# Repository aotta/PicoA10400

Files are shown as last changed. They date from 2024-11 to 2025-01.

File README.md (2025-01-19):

# PicoA10400
Flashcart for Atari 2600 and Atari 7800 based on Pico "Purple" clone, easy to build and cheap.
This is a "double-face" flashcart, it could be used for both Atari 2600 and Atari 7800, simply rotating it and inserting the cart in different Atari!!
It doesn't support all bank-switching schemas, but enough to enjoy your A2600 / A7800 with a single flash-carts!!

A special thanks to other opensource project for Atari multicarts from which i got a lot of info, ideas and also code:
https://github.com/robinhedwards/UnoCart-2600

https://github.com/karrika/Otaku-flash

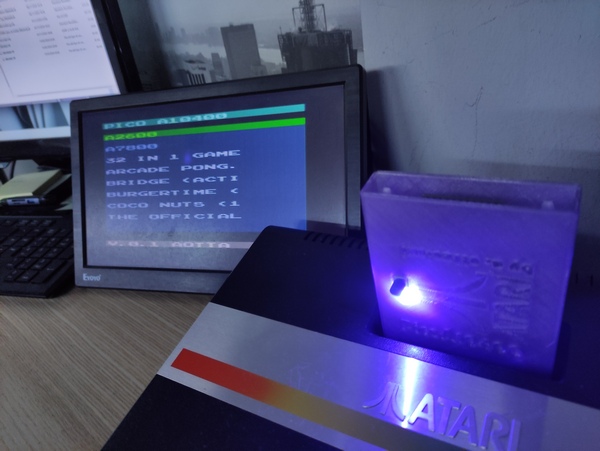
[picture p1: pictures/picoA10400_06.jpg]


**WARNING!** "purple" Pico has not the same pinout of original Raspberry "green" ones, you MUST use the clone or you may damage your hardware.
Also note that the battery used is a RECHARGEABLE LIR2032, if you want to use a NON reachargeable battery you must add a diode in circuit!!!

Tested only on PAL consoles so far, feel free to send comments and feedback on AtariAge thread:
https://forums.atariage.com/topic/374297-picoa10400-preview/

**NOTE** Please look at picture for soldering side of the components, or your shell won't close!! they are different from the pcb mask!!!

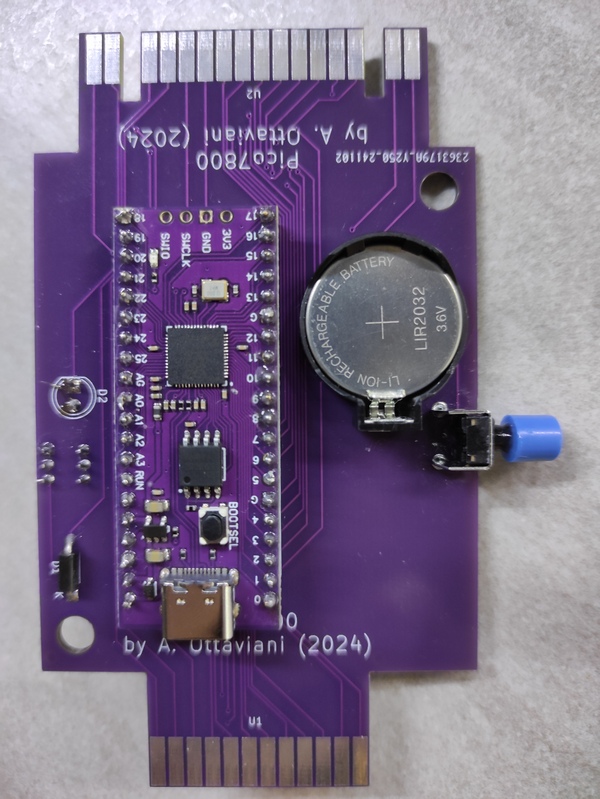
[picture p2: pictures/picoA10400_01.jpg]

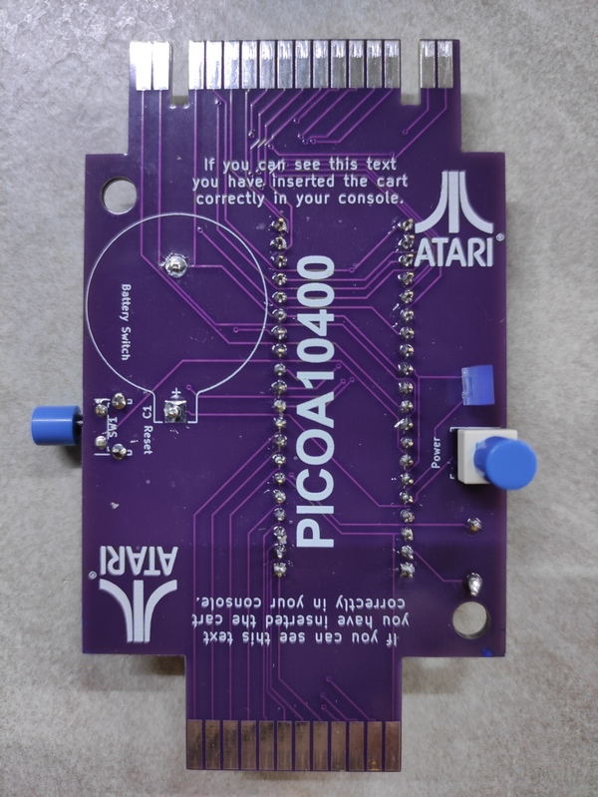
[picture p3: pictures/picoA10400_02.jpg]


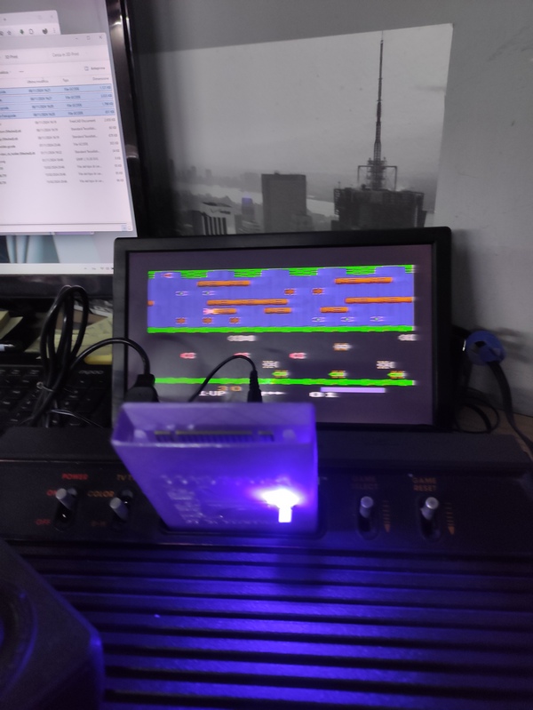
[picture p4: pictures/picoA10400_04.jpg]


Also added a Raspberry Pico 2 version, relative files are named Pico2A10400. It works but consider its smaller flash size for roms (3mb):

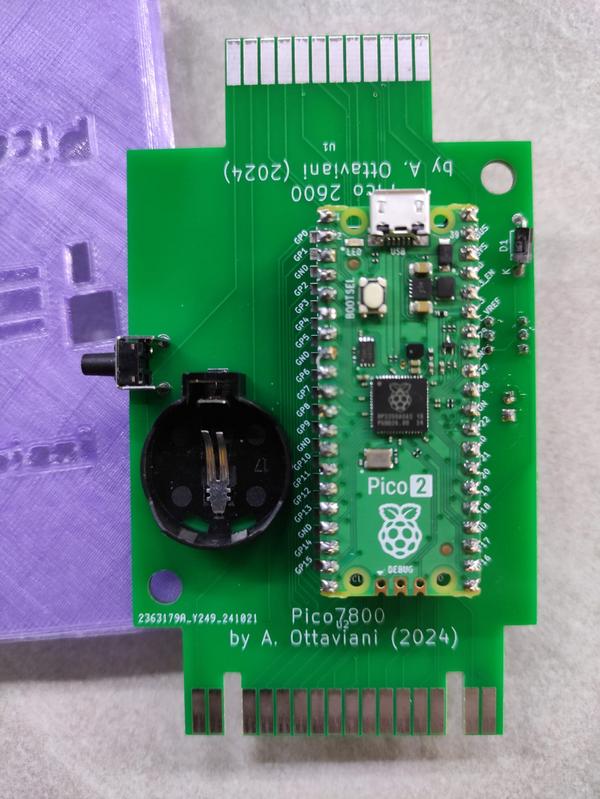
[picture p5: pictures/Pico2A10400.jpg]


Gerbers file are provided for the PCB, add you pico clone, and flash the firmware ".uf2" in the Pico by connecting it while pressing button on Pico and drop it in the opened windows on PC.
After flashed with firmware, and every time you have to change your ROMS repository, you can simply connect the Pico to PC and drag&drop "BIN" files  into.

**NOTE 2** Due to different timing of PicoA10400 and the Atari consoles, that can't be resetted, the flashcart MUST BE POWERED ON (with POWER SWITCH ON CART) BEFORE POWERING THE CONSOLE!!! Also, some games and ALL A7800 GAMES NEEDS THAT THE CONSOLE IS POWERED OFF THEN POWERED ON TO START!!!!

Even if the diode should protect your console, **DO NOT CONNECT PICO WHILE INSERTED IN A POWERED ON CONSOLE!**

19th january 2025: added Pico 10400 Alternative Version by XAD, with improvements in pcb and shell: https://www.nightfallcrew.com/17/01/2025/picoa10400-flashcart-for-atari-2600-7800/
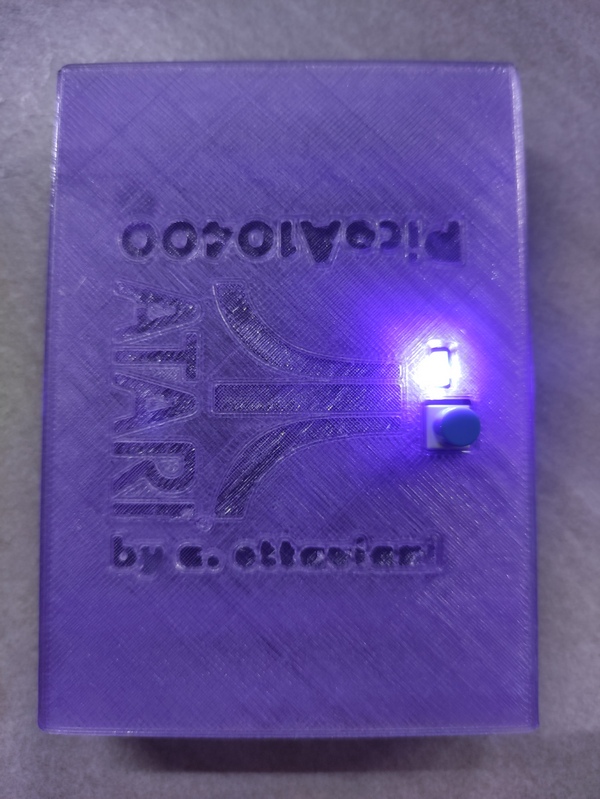
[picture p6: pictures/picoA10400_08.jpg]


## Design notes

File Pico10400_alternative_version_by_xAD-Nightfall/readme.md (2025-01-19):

3D Printer Model: Flsun v400
Filament: PLA+

Screws and micro switches:

M2 screws with countersunk head: https://www.amazon.it/dp/B0D3DXFGHW
Mini SPDT Switch: https://www.amazon.it/dp/B0BTM3WQXN

The LED source voltage is 3.3v from PIN 36 of the PICO Purple.

LED Resistor:

RED/YELLOW LED: 100ohm
GREEN LED: 75ohm
BLU/WHITE: No Resistor (solder a bridge instead of resistor)

Pico 10400 Main Project: https://github.com/aotta/PicoA10400
Pico 10400 Alternative Version: https://www.nightfallcrew.com/17/01/2025/picoa10400-flashcart-for-atari-2600-7800/

Xad/Nightfall

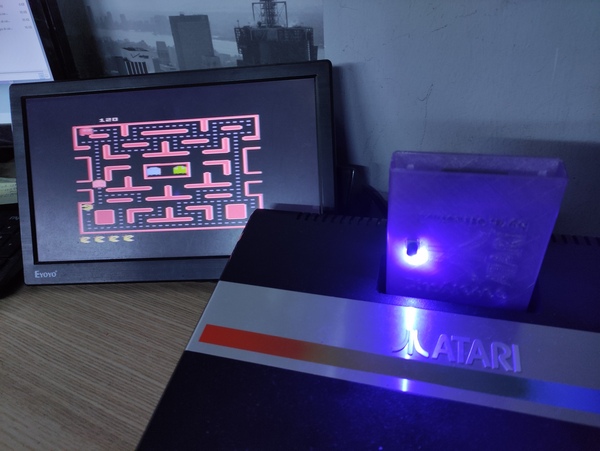
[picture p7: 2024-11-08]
pictures/picoA10400_11.jpg

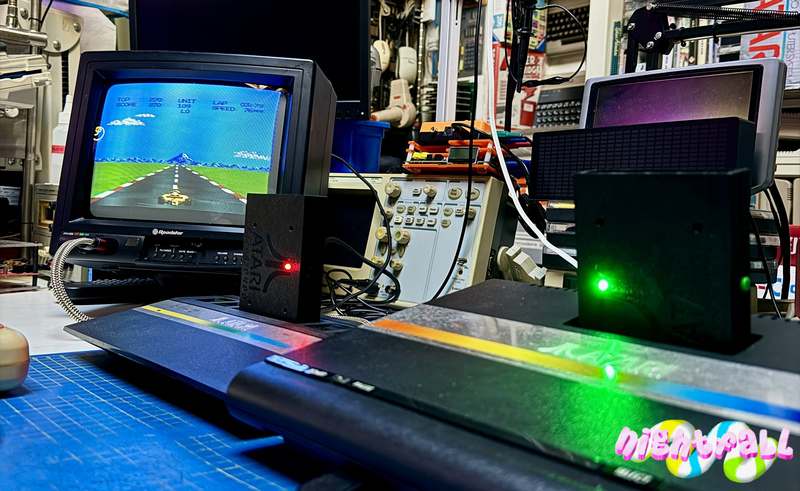
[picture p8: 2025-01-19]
pictures/picoA10400_09.jpg

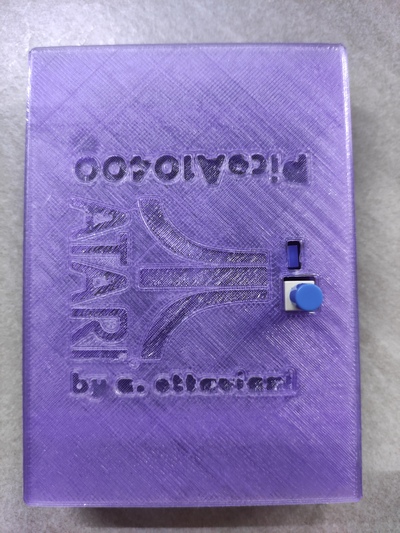
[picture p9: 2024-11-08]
pictures/picoA10400_07.jpg

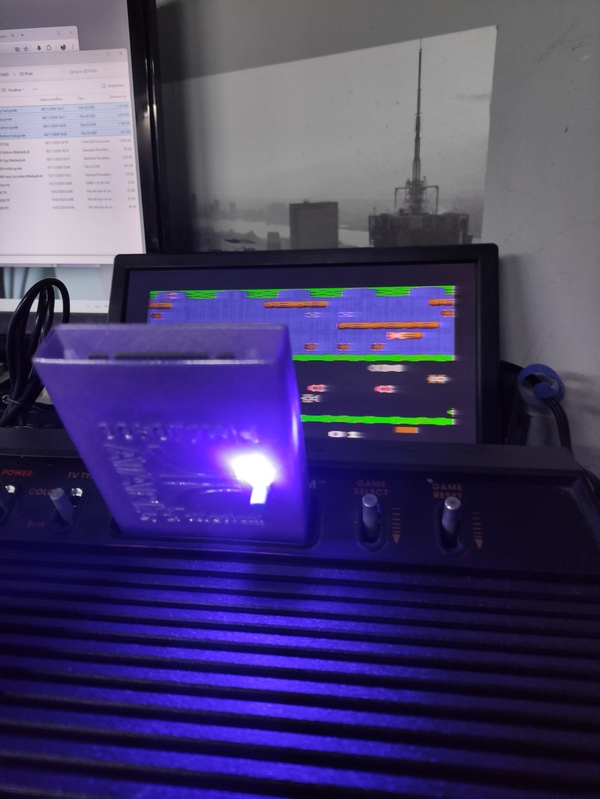
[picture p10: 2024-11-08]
pictures/picoA10400_05.jpg

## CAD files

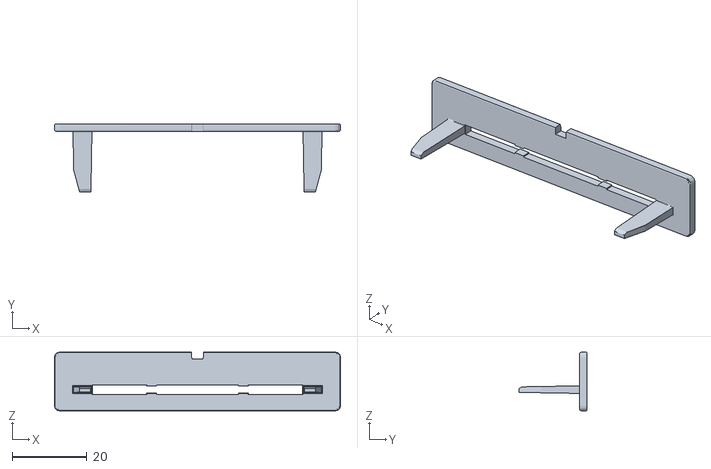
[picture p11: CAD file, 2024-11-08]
3D Print/PicoA10400-atari_cb_holder (Meshed).stl
76.4 x 18.3 x 15.7

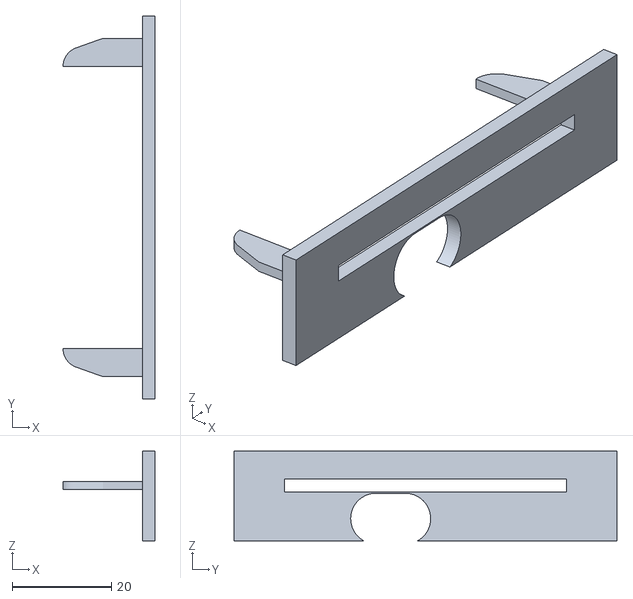
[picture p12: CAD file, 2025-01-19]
Pico10400_alternative_version_by_xAD-Nightfall/Stl/Holder usb.stl
18.5 x 77.0 x 18.0

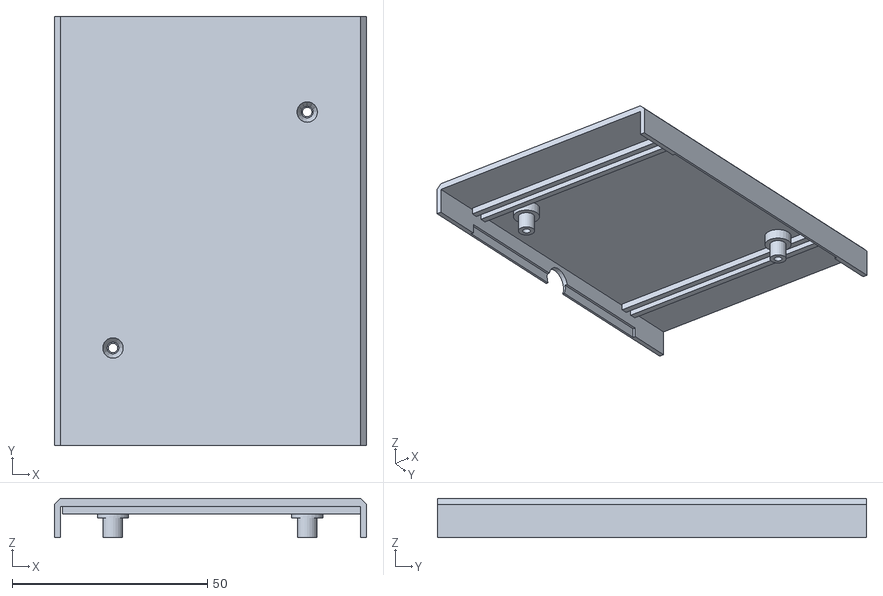
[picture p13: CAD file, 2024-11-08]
3D Print/PicoA10400-Bottom (Meshed).stl
80.0 x 110.0 x 10.0

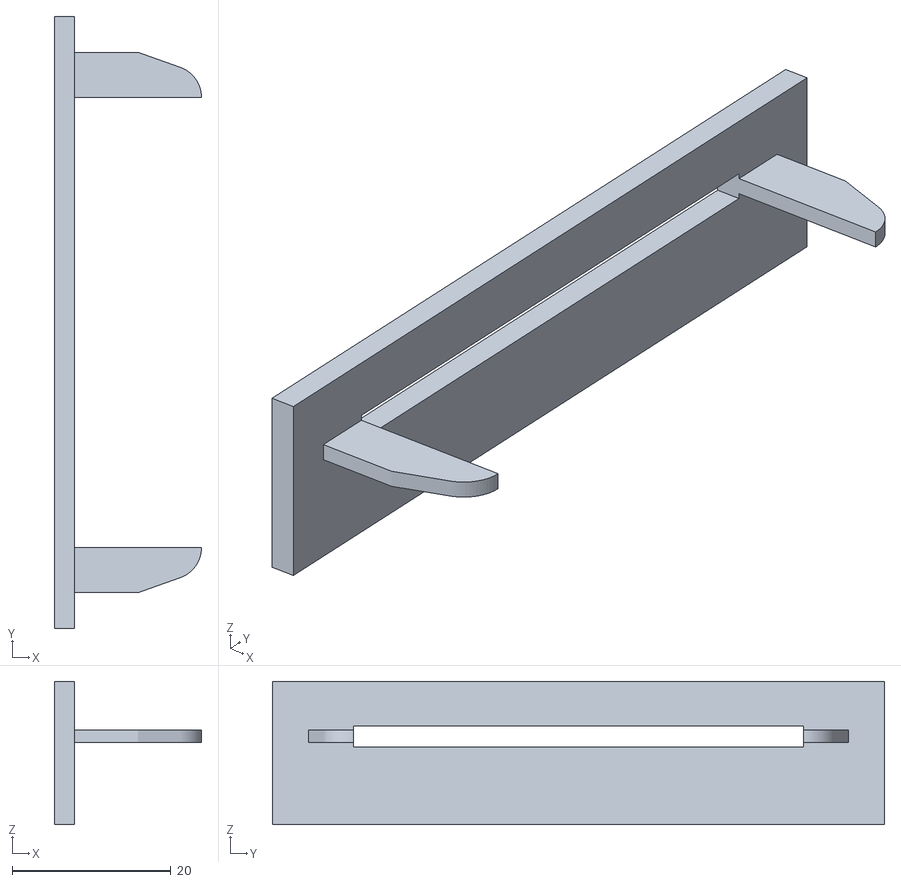
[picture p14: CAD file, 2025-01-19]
Pico10400_alternative_version_by_xAD-Nightfall/Stl/Holder.stl
18.5 x 77.0 x 18.0

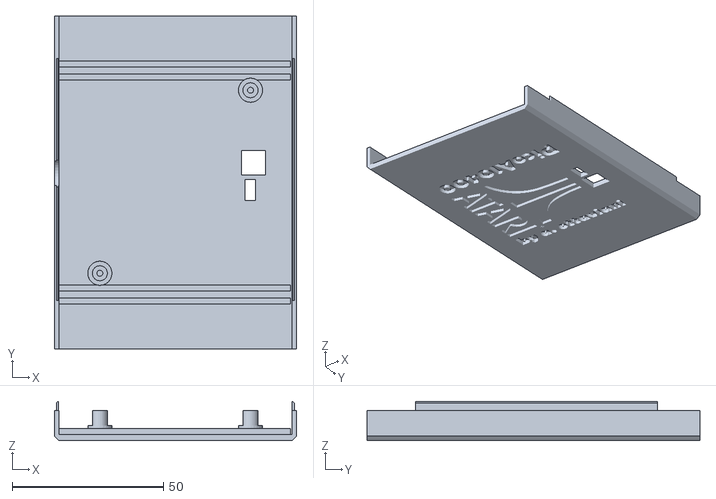
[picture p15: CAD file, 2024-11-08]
3D Print/PicoA10400-Top (Meshed).stl
80.0 x 110.0 x 13.0

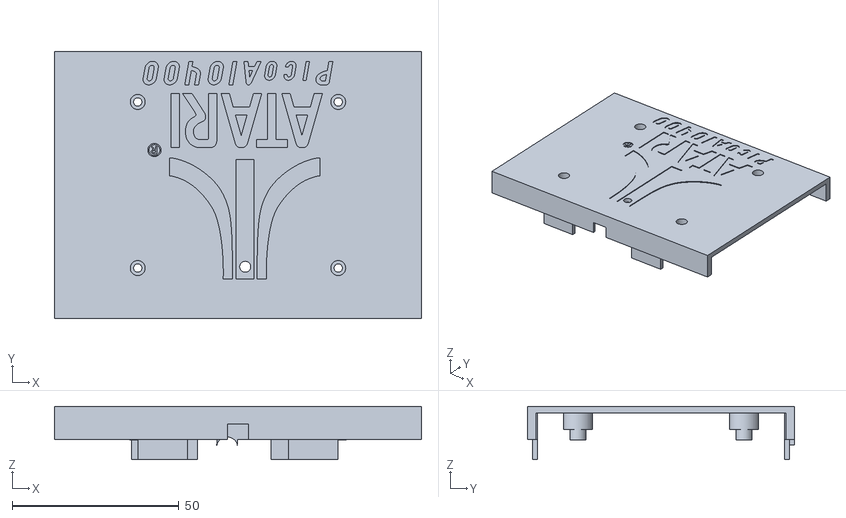
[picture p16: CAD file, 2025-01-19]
Pico10400_alternative_version_by_xAD-Nightfall/Stl/Top.stl
110.0 x 80.0 x 16.0

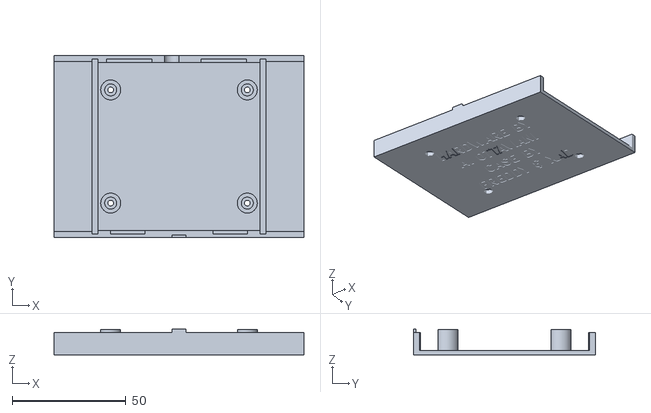
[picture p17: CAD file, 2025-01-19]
Pico10400_alternative_version_by_xAD-Nightfall/Stl/Bottom.stl
110.0 x 80.0 x 11.4

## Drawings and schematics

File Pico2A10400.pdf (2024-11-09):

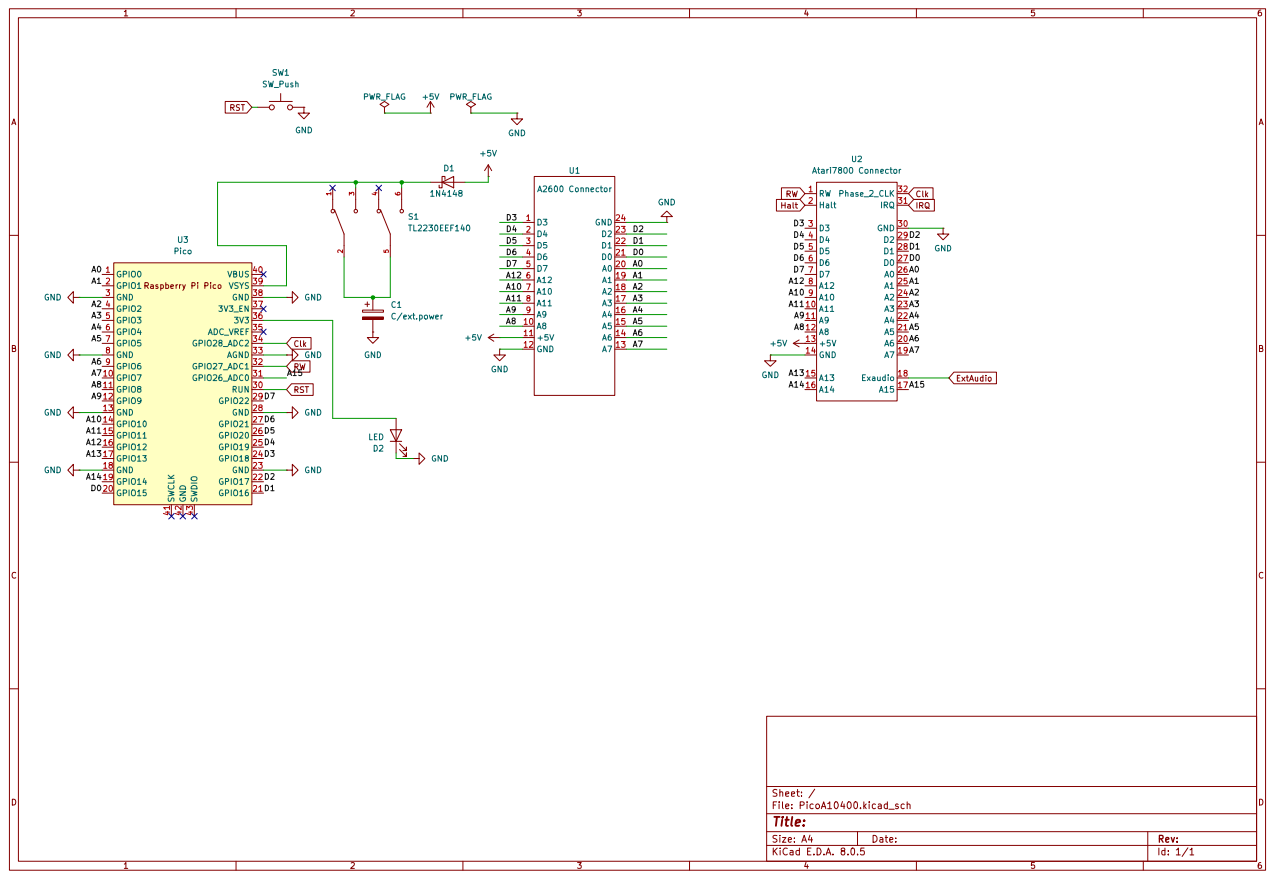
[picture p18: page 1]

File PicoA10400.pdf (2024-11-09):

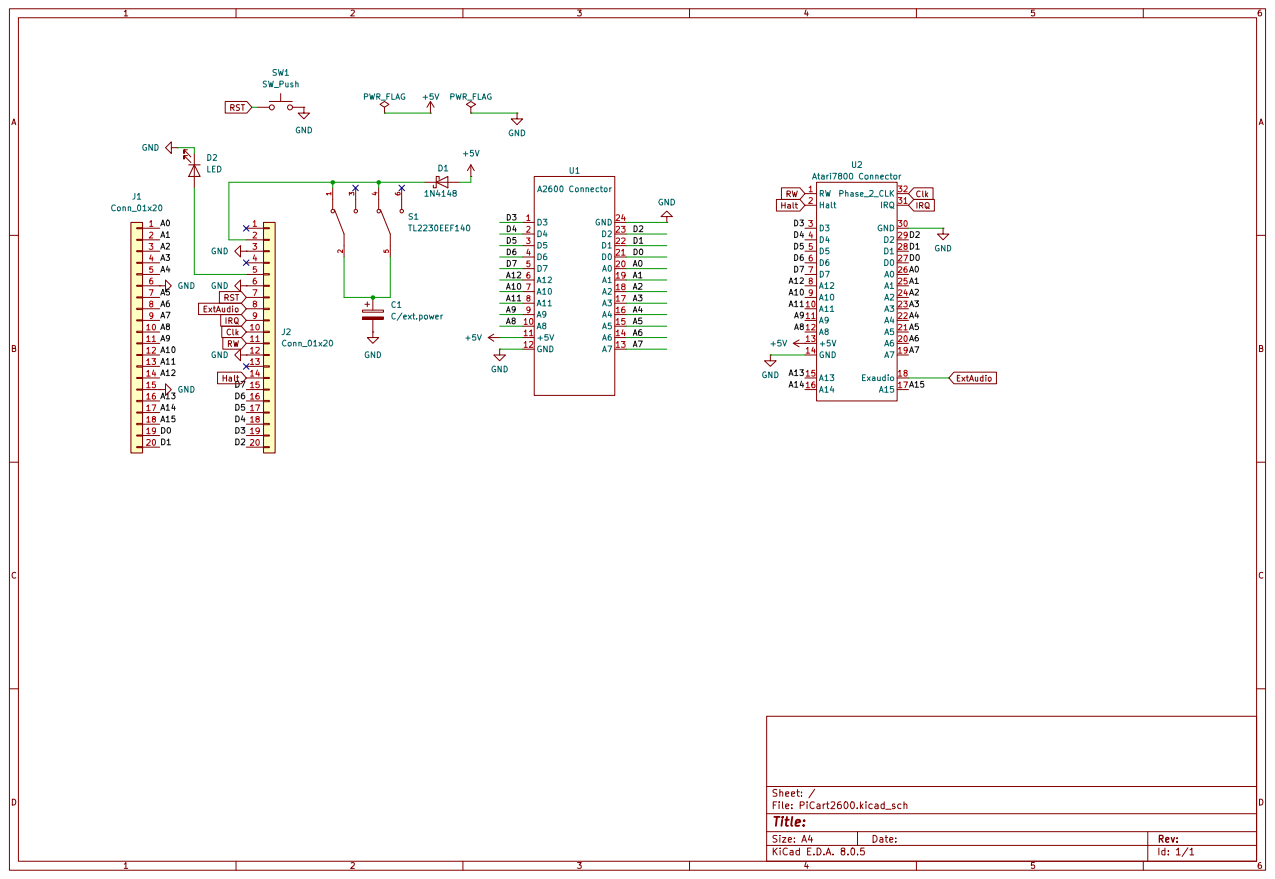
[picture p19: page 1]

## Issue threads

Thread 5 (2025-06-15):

Not filesystem

yoprogramo, 2025-06-15:
I have mounted the card and flashed the uf2 and the unit appears but without filesystem. Do I need to format it?

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

aotta, 2025-06-15:
some users reported issue in detecting flash in non "windows" systems. Please use PC with MS Windows OS for loading roms.

yoprogramo, 2025-06-15:
I have not a windows machine and I don't wanna to buy one for this. I'll try to enhance the code to avoid this dependency if it is possible.

Thank you

yoprogramo, 2025-06-17:
I'm trying to compile the code using platformio but I have errors compiling the libraries used. Do you have some instructions on compiling it?

Regards

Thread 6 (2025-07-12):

No Menu with 2600+

JmanNZ, 2025-07-12:
No menu with Atari 2600+.
1st game in the list loads and plays fine

Regards

aotta, 2025-07-12:
I have no 2600+ to test, but other users reported PicoA10400 worked fine with it

douglie007, 2025-08-04:
I also have the same issue with the 2600+.  only way I can play a game on it  would be to load the game on an original console, leave the cart on and boot it in the 2600+ and it will pull the game.  but I don't know how you could use the menu in a 2600+ because the console just rips the ROM from the cart and loads it up in Stella emulator, it would have to be able to rip the menu and all the games on the Pico.

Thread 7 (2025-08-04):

Testing 7800 side of cart has issues.

douglie007, 2025-08-04:
When I try and load a 7800 game, if I use the .BIN i just get noise, If I use the .a78 files I can boot the game after power cycling the console. Even so the games that are at 128K have a hard time playing.  I couldnt find a instruction manual on what to expect, this i might be normal.    A request would be, can the games be saved in a ROM instead of in the RAM?  It would be nice if it held the game in a state where you dont need to worry about the battery it would would on the 2600+ and 7800+.

Thanks for the great work youve done with this!

Closed 2025-08-04.

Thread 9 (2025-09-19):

Add support for the A7800+ and A2600+

SolverTwins, 2025-09-19:
Thanks for your fabulous Job, I will trying to modify, adding support for the a7800+ and a2600+, my solution is add a 2 lines LCD panel (I2C) connected directly to the PICO and obtain the 5v from the cart/console , and add 3 buttons to navigate in the LCD, so you can select the game to be presented to the console, and you only need then to reset the console (not the a10400) and voila the game will work, I think that its posible, please can you tell me what do you think, THANKS

aotta, 2025-09-20:
Yes, it's possible in theory, but it would be a massive change in logic, code and scope of the project.
I'm not interested in supporting new consoles nor i have a "+" Atari emulator, but source are here if someone want to use it for a a2600+ or a7800+ project.

Closed 2025-09-20.

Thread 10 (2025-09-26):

Power and alternate microcontroller question.

MarkMccabe, 2025-09-26:
More of some questions instead of "hard issues".
A) If I use a PICO2 instead of the A10400 do I still need to make sure it is powered up before the Atari console or is that just a A10400 issue?
B) I already have a batch of Raspberry Pi Picos. Can I use them instead of the Pico2 even though they are a bit slower. (Actually I have the Chinese clone of the Pi Pico with the multicolor LED and larger program storage space)
C) Also my machines are NTSC. Has the NTSC menu open issue been resolved or should I wait until it is before procuring and building these?
A big thank you for designing this!!! I will build some of them as soon as I know if the menu works on NTSC. Wonderful Project!!! Thanks again!!!

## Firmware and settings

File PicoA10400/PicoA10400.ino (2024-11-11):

/*
//            PICO A10400 an Atari 2600+7800 MultiCART by Andrea Ottaviani 
// Atari 2600 / Atari 7800   multicart based on Raspberry Pico board -

// v. 0.1 2024-10-03 : Initial version for Pi Pico 
//
// 
//  More info on https://github.com/aotta/ 
*/

#include "hardware/gpio.h"
#include "pico/platform.h"
#include "pico/stdlib.h"
#include "hardware/vreg.h"
#include "pico/multicore.h"
#include "hardware/flash.h"
#include "hardware/sync.h"
#include "string.h"
#include "rom.h"
//#include "menu7800.h"

// include for Flash files
#include "SPI.h"
#include "SdFat.h"
#include "Adafruit_SPIFlash.h"
#include "Adafruit_TinyUSB.h"
#include "supercharger_bios.h"
Adafruit_FlashTransport_RP2040 flashTransport;
Adafruit_SPIFlash flash(&flashTransport);

// file system object from SdFat
FatVolume fatfs;
FatFile root;
FatFile file;

// USB Mass Storage object
Adafruit_USBD_MSC usb_msc;
// Check if flash is formatted
bool fs_formatted;
// Set to true when PC write to flash
bool fs_changed;

#define a7800    0   // 1 for 7800 menu, 0 for 2600

// Pico pin usage definitions

#define A0_PIN    0
#define A1_PIN    1
#define A2_PIN    2
#define A3_PIN    3
#define A4_PIN    4
#define A5_PIN    5
#define A6_PIN    6
#define A7_PIN    7
#define A8_PIN    8
#define A9_PIN    9
#define A10_PIN  10
#define A11_PIN  11
#define A12_PIN  12
#define A13_PIN  13
#define A14_PIN  14
#define A15_PIN  15
#define D0_PIN   16
#define D1_PIN   17
#define D2_PIN   18
#define D3_PIN   19
#define D4_PIN   20
#define D5_PIN   21
#define D6_PIN   22
#define D7_PIN   23
#define HALT_PIN 24
#define RW_PIN   26
#define CLK_PIN  27
#define IRQ_PIN  28

// Pico pin usage masks
#define A0_PIN_MASK     0x00000001L //gpio 0
#define A1_PIN_MASK     0x00000002L
#define A2_PIN_MASK     0x00000004L
#define A3_PIN_MASK     0x00000008L
#define A4_PIN_MASK     0x00000010L
#define A5_PIN_MASK     0x00000020L
#define A6_PIN_MASK     0x00000040L
#define A7_PIN_MASK     0x00000080L
#define A8_PIN_MASK     0x00000100L
#define A9_PIN_MASK     0x00000200L
#define A10_PIN_MASK    0x00000400L
#define A11_PIN_MASK    0x00000800L
#define A12_PIN_MASK    0x00001000L  //  
#define A13_PIN_MASK    0x00002000L  //  
#define A14_PIN_MASK    0x00004000L  //  
#define A15_PIN_MASK    0x00008000L  //  
#define D0_PIN_MASK     0x00010000L
#define D1_PIN_MASK     0x00020000L
#define D2_PIN_MASK     0x00040000L
#define D3_PIN_MASK     0x00080000L
#define D4_PIN_MASK     0x00100000L  // gpio 20
#define D5_PIN_MASK     0x00200000L
#define D6_PIN_MASK     0x00400000L
#define D7_PIN_MASK     0x00800000L //gpio 23
#define HALT_PIN_MASK   0x01000000L //gpio 24
#define LED_PIN_MASK    0x02000000L //gpio 25
#define RW_PIN_MASK     0x04000000L //gpio 26
#define CLK_PIN_MASK    0x08000000L //gpio 27
#define IRQ_PIN_MASK    0x10000000L //gpio 28


// Aggregate Pico pin usage masks
#define ALL_GPIO_MASK  	0x1FFFFFFFL
#define BUS_PIN_MASK    0x0000FFFFL
#define BUS_H_PIN_MASK  0x0000E000L
#define DATA_PIN_MASK   0x00FF0000L
#define STATUS_PIN_MASK 0x1D000000L
#define READ_PIN_MASK    (A14_PIN_MASK | A15_PIN_MASK | RW_PIN_MASK)  //gpio 27

#define ALWAYS_IN_MASK  (BUS_PIN_MASK | STATUS_PIN_MASK)
#define ALWAYS_OUT_MASK (DATA_PIN_MASK)

#define SET_DATA_MODE_OUT   gpio_set_dir_out_masked(DATA_PIN_MASK)
#define SET_DATA_MODE_IN    gpio_set_dir_in_masked(DATA_PIN_MASK)

#define SET_LED_ON    	gpio_init(25);gpio_set_dir(25,GPIO_OUT);gpio_put(25,true);
#define SET_LED_OFF    	gpio_init(25);gpio_set_dir(25,GPIO_OUT);gpio_put(25,false);



#define CART_TYPE_NONE	0
#define CART_TYPE_2K	1
#define CART_TYPE_4K	2
#define CART_TYPE_F8	3	// 8k
#define CART_TYPE_F6	4	// 16k
#define CART_TYPE_F4	5	// 32k
#define CART_TYPE_F8SC	6	// 8k+ram
#define CART_TYPE_F6SC	7	// 16k+ram
#define CART_TYPE_F4SC	8	// 32k+ram
#define CART_TYPE_FE	9	// 8k
#define CART_TYPE_3F	10	// varies (examples 8k)
#define CART_TYPE_3E	11	// varies (only example 32k)
#define CART_TYPE_3EX   12
#define CART_TYPE_E0	13	// 8k
#define CART_TYPE_0840	14	// 8k
#define CART_TYPE_CV	15	// 2k+ram
#define CART_TYPE_EF	16	// 64k
#define CART_TYPE_EFSC	17	// 64k+ram
#define CART_TYPE_F0	18	// 64k
#define CART_TYPE_FA	19	// 12k
#define CART_TYPE_E7	20	// 16k+ram
#define CART_TYPE_DPC	21	// 8k+DPC(2k)
#define CART_TYPE_AR	22  // Arcadia Supercharger (variable size)
#define CART_TYPE_BF	23  // BF
#define CART_TYPE_BFSC	24  // BFSC
#define CART_TYPE_ACE	25  // ARM Custom Executable
#define CART_TYPE_PP    26  // Pink Panther Prototype
#define CART_TYPE_DF    27  // DF
#define CART_TYPE_DFSC  28  // DFSC
#define CART_TYPE_3EP	29	// 3E+ 1-64K + 32K ram
#define CART_TYPE_4KSC  30  // 4k+SC
#define CART_TYPE_FA2	31	// 28k
#define CART_TYPE_A78	32	// Atari 7800
#define CART_TYPE_NORMALA78	33	// Atari 7800
#define CART_TYPE_ABSOLUTE	34	// Atari 7800
#define CART_TYPE_ACTIVISION	35	// Atari 7800
#define CART_TYPE_SUPERCART_EF	36	// Atari 7800 supercart EX-FIX
#define CART_TYPE_SUPERCART_ROM	37	// Atari 7800
#define CART_TYPE_SUPERCART_RAM	38	// Atari 7800
#define CART_TYPE_SUPERCART_LARGE	39	// Atari 7800
#define CART_TYPE_SUPERCART	40	// Atari 7800 supercart bs

#define CCM_RAM ((uint8_t*)0x10000000)
#define CCM_SIZE (64 * 1024)

#define RAM_BANKS 48
#define CCM_BANKS 32

#define MAX_RAM_BANK (RAM_BANKS - 1)
#define MAX_CCM_BANK (MAX_RAM_BANK + CCM_BANKS)

typedef struct __attribute__((packed)) {
	uint8_t entry_lo;
	uint8_t entry_hi;
	uint8_t control_word;
	uint8_t block_count;
	uint8_t checksum;
	uint8_t multiload_id;
	uint8_t progress_bar_speed_lo;
	uint8_t progress_bar_speed_hi;
	uint8_t padding[8];
	uint8_t block_location[48];
	uint8_t block_checksum[48];
} LoadHeader;

typedef struct __attribute__((packed)) {
	uint8_t magic_number[8]; // Always ascii "ACE-2600"
	uint8_t driver_name[16]; // emulators care about this
	uint32_t driver_version; // emulators care about this
	uint32_t rom_size;		 // size of ROM to be copied to flash, 448KB max
	uint32_t rom_checksum;	 // used to verify if flash already contains valid image
	uint32_t entry_point;	 // where to begin executing
} ACEFileHeader;

typedef struct {
	const char *ext;
	int cart_type;
} EXT_TO_CART_TYPE_MAP;

EXT_TO_CART_TYPE_MAP ext_to_cart_type_map[] = {
	{"ROM", CART_TYPE_NONE},
	{"BIN", CART_TYPE_NONE},
	{"A26", CART_TYPE_NONE},
	{"2K", CART_TYPE_2K},
	{"4K", CART_TYPE_4K},
	{"F8", CART_TYPE_F8},
	{"F6", CART_TYPE_F6},
	{"F4", CART_TYPE_F4},
	{"F8S", CART_TYPE_F8SC},
	{"F6S", CART_TYPE_F6SC},
	{"F4S", CART_TYPE_F4SC},
	{"FE", CART_TYPE_FE},
	{"3F", CART_TYPE_3F},
	{"3E", CART_TYPE_3E},
	{"3EX", CART_TYPE_3E},
	{"3EP", CART_TYPE_3EP},
	{"E0", CART_TYPE_E0},
	{"084", CART_TYPE_0840},
	{"CV", CART_TYPE_CV},
	{"EF", CART_TYPE_EF},
	{"EFS", CART_TYPE_EFSC},
	{"F0", CART_TYPE_F0},
	{"FA", CART_TYPE_FA},
	{"E7", CART_TYPE_E7},
	{"DPC", CART_TYPE_DPC},
	{"AR", CART_TYPE_AR},
	{"BF", CART_TYPE_BF},
	{"BFS", CART_TYPE_BFSC},
	{"ACE", CART_TYPE_ACE},
	{"WD", CART_TYPE_PP},
	{"DF", CART_TYPE_DF},
	{"DFS", CART_TYPE_DFSC},
	{"4KSC", CART_TYPE_4KSC},
  {"FA2", CART_TYPE_FA2},
  {"A78", CART_TYPE_A78},
	{0,0}
};

//#define rom_table_SIZE			128  // kilobytes
unsigned int cart_size_bytes;

//unsigned char rom_table[32*1024];
char menu_status[16];
uint8_t AR_ROM[8448*4];
char filelist[85*48]; // 85 name of 48 chars max lenght
uint8_t ram_table[32*1024];
char path[128];
 char filetoopen[50];
 
char menu_ram[1024];	// < NUM_DIR_ITEMS * 12 (85 max)
char isfor7800=0;
char is16k=0;
int romsize;
int lastpos;
volatile u_int8_t bank_type=1;
volatile u_int8_t new_bank_type=1;
volatile int romLen=0;
u_int8_t gamechoosen=0;
volatile u_int8_t newgame=0;
volatile u_int8_t rootdir=0;
volatile uint32_t addrc;
volatile uint32_t retaddr;
volatile u_int8_t cart_to_emulate;
  
////////////////////////////////////////////////////////////////////////////////////
//                     REBOOT
////////////////////////////////////////////////////////////////////////////////////
void doReboot() {
  rp2040.reboot();
}
////////////////////////////////////////////////////////////////////////////////////
//                     EXIT CARTRIDGE
////////////////////////////////////////////////////////////////////////////////////

void exit_cartridge(uint32_t addr, uint32_t addr_prev){
         
  gpio_put_masked(DATA_PIN_MASK,0xEA<<D0_PIN);    // (NOP) or data for SWCHB
	SET_DATA_MODE_OUT;
	while ((gpio_get_all()&BUS_PIN_MASK) == addr);

	addr = gpio_get_all()&BUS_PIN_MASK;
	 gpio_put_masked(DATA_PIN_MASK,0x00<<D0_PIN); // (BRK)
  while ((gpio_get_all()&BUS_PIN_MASK) == addr);
}
////////////////////////////////////////////////////////////////////////////////////
//                    reboot CARTRIDGE
////////////////////////////////////////////////////////////////////////////////////

void reboot_cartridge(uint32_t addr, uint32_t addr_prev){
retry:
  while(!(addr=gpio_get_all()&BUS_PIN_MASK) & 0x1000);
  gpio_put_masked(DATA_PIN_MASK,0x6c<<D0_PIN);    // (NOP) or data for SWCHB
	SET_DATA_MODE_OUT;
	while ((gpio_get_all()&BUS_PIN_MASK) == addr);
  
  addr = gpio_get_all()&BUS_PIN_MASK;
	 gpio_put_masked(DATA_PIN_MASK,0xfc<<D0_PIN); // (BRK)
 
  while ((gpio_get_all()&BUS_PIN_MASK) == addr);
   
   gpio_put_masked(DATA_PIN_MASK,0xff<<D0_PIN); // (BRK)
  while ((gpio_get_all()&BUS_PIN_MASK) == addr);
  //if ((gpio_get_all()&BUS_PIN_MASK) != 0xfffc) goto retry;
}

////////////////////////////////////////////////////////////////////////////
void __time_critical_func(emulate_activision()) {

  /*-------------------------------------------------

 Carts with Activision bankswitch:
 128K games. 8 x 16K banks (0-7) to be mapped at
 0xa000-0xdfff. Bank is selected by writing above
 0xe000 and depends on A2-A0.
 The rest of the memory is as follows:
 0x4000-0x7fff bank 6
 0x8000-0x9fff first 8K of bank 7
 0xe000-0xffff second 8K of bank 7
 GAMES: Double Dragon, Rampage.
 -------------------------------------------------*/
      uint32_t bank=0, addr=0, addr_prev=0, rawaddr=0;
      uint8_t rom_in_use=1;
      uint32_t write_mask=(RW_PIN_MASK | A15_PIN_MASK | A14_PIN_MASK | A13_PIN_MASK );
      while (1) {    // Get address
             // Get address
         	  while ((addr = (gpio_get_all()&BUS_PIN_MASK)) != addr_prev)
			        addr_prev = addr;
            
            //addr = (gpio_get_all()&BUS_PIN_MASK);
			      
            if ((gpio_get_all()&RW_PIN_MASK)==0) {
                if (addr>=0xff80)  bank= (gpio_get_all() & 7) * 0x4000;
              } else {
	          if ((addr>=0x4000)&&(addr<=0x7fff)) { // 0x4000-0x7fff bank 6
	            gpio_put_masked(DATA_PIN_MASK, rom_table[(addr & 0x3fff) + 0x18000] << D0_PIN);
              SET_DATA_MODE_OUT;
              while ((gpio_get_all()&BUS_PIN_MASK)==addr);
              SET_DATA_MODE_IN;
			      } else
            if ((addr>=0x8000)&&(addr<=0x9fff)) { // first 8k bank 7
	            gpio_put_masked(DATA_PIN_MASK, rom_table[(addr& 0x3fff)+ 0x1c000] << D0_PIN);
              SET_DATA_MODE_OUT;
              while ((gpio_get_all()&BUS_PIN_MASK)==addr);
              SET_DATA_MODE_IN;
			      } else
            if ((addr>=0xe000)&&(addr<=0xffff)) { // second 8k bank 7
                    gpio_put_masked(DATA_PIN_MASK, rom_table[(addr & 0x3fff)+ 0x1c000] << D0_PIN);
                SET_DATA_MODE_OUT;
                while ((gpio_get_all()&BUS_PIN_MASK)==addr);
                SET_DATA_MODE_IN;
            } else
            if ((addr>=0xa000)&&(addr<=0xdfff)) { 
                  gpio_put_masked(DATA_PIN_MASK, rom_table[(addr & 0x3fff ) + bank] << D0_PIN);
              SET_DATA_MODE_OUT;
              while ((gpio_get_all()&BUS_PIN_MASK)==addr);
              SET_DATA_MODE_IN;
            } 
          }
        } 
      }	              
  
    

void __time_critical_func(emulate_supercart_ef()) {
      uint32_t bank=0, addr=0, addr_prev=0, rawaddr=0;
      uint8_t rom_in_use=1;
      
      while (1) {    // Get address
             // Get address
        rawaddr = gpio_get_all();
        addr = rawaddr & BUS_PIN_MASK;
        // Check for A15
        if (addr & A15_PIN_MASK) {
            // Check for A14
            if (addr & A14_PIN_MASK) {
                // Set the data on the bus for fixed bank 7
                gpio_put_masked(DATA_PIN_MASK, rom_table[addr + 0x10000] << D0_PIN);
                rawaddr = gpio_get_all() & READ_PIN_MASK;
	          if (rawaddr == READ_PIN_MASK) {
                    // Read cycle
                    if (!rom_in_use) {
                        SET_DATA_MODE_OUT;
                        rom_in_use = 1;
                    }
                }
            } else {
                // Set the data on the bus for active bank
                gpio_put_masked(DATA_PIN_MASK, rom_table[(addr & 0x3fff) + bank] << D0_PIN);
                // Check for RW
                rawaddr = gpio_get_all() & READ_PIN_MASK;
	          if (rawaddr == (RW_PIN_MASK | A15_PIN_MASK)) {  // READ ROM
                    // Read cycle
                    if (!rom_in_use) {
                       SET_DATA_MODE_OUT;
                       rom_in_use = 1;
                    }
                } else {  // Write cycle to ROM
                   // rawaddr = gpio_get_all() & (RW_PIN_MASK | A15_PIN_MASK);
                    rawaddr = gpio_get_all() & (RW_PIN_MASK | A15_PIN_MASK);
                    // Check for bankswitch
                    if (rawaddr == A15_PIN_MASK) {
                        // Bankswitching write
                        SET_DATA_MODE_IN;
                        // Check for 0x01
                        rawaddr = gpio_get_all();
                        bank=((rawaddr >> D0_PIN) & 0xf)*0x4000;
                        rom_in_use = 0;
                    }
                }
            }
        } else {
            // EXFIX - bank 6 is in 0x4000
            if (addr & 0x4000) {
                gpio_put_masked(DATA_PIN_MASK, rom_table[(addr & 0x3fff) + 0x18000] << D0_PIN);
                rawaddr = gpio_get_all() & (RW_PIN_MASK | A14_PIN_MASK);
	        if (rawaddr == (RW_PIN_MASK | A14_PIN_MASK)) {
                    // Read cycle
                    if (!rom_in_use) {
                        SET_DATA_MODE_OUT;
                        rom_in_use = 1;
                    }
                } else {
                    if (rom_in_use) {
                        SET_DATA_MODE_IN;
                        rom_in_use = 0;
                    }
                }
            } else {
                if (rom_in_use) {
                    SET_DATA_MODE_IN;
                    rom_in_use = 0;
                }
            }
        }
      }
    }

void __time_critical_func(emulate_supercart_ram()) {
      uint32_t bank=0;
      uint32_t addr=0, addr_prev=0, rawaddr=0;
      uint8_t rom_in_use=1;
      
      while (1) {    // Get address
             // Get address
        rawaddr = gpio_get_all();
        addr = rawaddr & BUS_PIN_MASK;
        // Check for A15
        if (addr & A15_PIN_MASK) {
            // Check for A14
            if (addr & A14_PIN_MASK) {
                // Set the data on the bus for fixed bank 7
                gpio_put_masked(DATA_PIN_MASK, rom_table[(addr & 0x7fff) + romLen - 0x8000 ] << D0_PIN);
                rawaddr = gpio_get_all() & READ_PIN_MASK;
	          if (rawaddr == READ_PIN_MASK) {
                    // Read cycle
                    if (!rom_in_use) {
                        SET_DATA_MODE_OUT;
                        rom_in_use = 1;
                    }
                }
            } else {
                // Set the data on the bus for active bank
                //gpio_put_masked(DATA_PIN_MASK, rom_table[(addr & 0x3fff) + bank] << D0_PIN);
                gpio_put_masked(DATA_PIN_MASK, rom_table[(addr & 0x7fff) + bank] << D0_PIN);
                // Check for RW
                rawaddr = gpio_get_all() & READ_PIN_MASK;
	          if (rawaddr == (RW_PIN_MASK | A15_PIN_MASK)) {  // READ ROM
                    // Read cycle
                    if (!rom_in_use) {
                       SET_DATA_MODE_OUT;
                       rom_in_use = 1;
                    }
                } else {  // Write cycle to ROM
                   // rawaddr = gpio_get_all() & (RW_PIN_MASK | A15_PIN_MASK);
                    rawaddr = gpio_get_all() & (RW_PIN_MASK | A15_PIN_MASK);
                    // Check for bankswitch
                    if (rawaddr == A15_PIN_MASK) {
                        // Bankswitching write
                        SET_DATA_MODE_IN;
                        // Check for 0x01
                        rawaddr = gpio_get_all();
                        bank=((rawaddr >> D0_PIN) & 0xf)*0x4000;
                        rom_in_use = 0;
                    }
                }
            }
        } else {
            rawaddr=gpio_get_all();
            // EXram - 16k is in 0x4000
            if (rawaddr & 0x4000) {
                addr= rawaddr & 0x3fff;
                gpio_put_masked(DATA_PIN_MASK, ram_table[addr] << D0_PIN);
                rawaddr = gpio_get_all() & (RW_PIN_MASK | A14_PIN_MASK);
	        if (rawaddr == (RW_PIN_MASK | A14_PIN_MASK)) {
                    // Read cycle
                    if (!rom_in_use) {
                        SET_DATA_MODE_OUT;
                        rom_in_use = 1;
                    }
                } else {
                  if (rawaddr == A14_PIN_MASK) {
                     // Write cycle
                        SET_DATA_MODE_IN;
                        rawaddr = gpio_get_all();
                        ram_table[rawaddr & 0x3fff] = (rawaddr >> D0_PIN) & 0xff;
                        rom_in_use = 0;
                  } else {
                    if (rom_in_use) {
                        SET_DATA_MODE_IN;
                        rom_in_use = 0;
                    }
                  }
                }
            } else {
                if (rom_in_use) {
                    SET_DATA_MODE_IN;
                    rom_in_use = 0;
                }
            }
        }
      }
}
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
void loop() 
{
  u_int8_t gc=0;
  
  bool menuletto=false;
  Serial.println("Opening root");
  strcpy(path,"/");
    if ( !root.open(path) ) {
      Serial.println("open root failed");
      while(1);
    }

    Serial.println("Flash contents:");

    // Open next file in root.
    // Warning, openNext starts at the current directory position
    // so a rewind of the directory may be required.
    
     set_menu_status_msg("V.0.1 AOTTA ");
   	 set_menu_status_byte(0);

  int i=0;
  int cmd_exec=0; // start with read files
  // Initialize GPIO pins
  Serial.println("waiting commands..");
 
  while (1) {
  if (retaddr>=CART_CMD_SEL_ITEM_n) {
    if (retaddr==CART_CMD_ROOT_DIR) {
      retaddr=0;
      AtariMenu(1);
      menuletto=1;
    } else if (menuletto) {
      gamechoosen = retaddr-CART_CMD_SEL_ITEM_n;
      Serial.print("Selected:");Serial.println(gamechoosen);
      AtariMenu(2);
      if (newgame==0){
          AtariMenu(1);     
          delay(280);
      }
         retaddr=0;
      //delay(100);
      } 
      retaddr=0;
    }

   if (cmd_exec!=0) {
    Serial.print("GC:");Serial.println(gamechoosen);
    delay(500);
   }
  }
   
 }

////////////////////////////////////////////////////////////////////////////////////
//                     MAIN LOOP
////////////////////////////////////////////////////////////////////////////////////    
  
void loop1()
{
     
}

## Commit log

2024-11-08 Add files via upload
    initial load
    [PicoA10400-Bottom (Meshed).stl, PicoA10400-Top (Meshed).stl, PicoA10400-atari_cb_holder (Meshed).stl]
2024-11-09 Create Pico2A10400
    Added version for Raspberry Pico 2 RP2350
2024-11-09 Add files via upload
    added schematics
2025-01-19 Add files via upload
    added XaD version
    [Bottom.stl, Holder usb.stl, Holder.stl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]
2026-08-23 Update README with fork information and soldering note
    Added information about a forked code with upgrades and optimizations.
